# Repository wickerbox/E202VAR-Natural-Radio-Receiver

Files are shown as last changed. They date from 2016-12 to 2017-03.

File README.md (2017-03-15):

## Introduction

This project is based on the Explorer E202, with permission. 

Renato Romero put plans online for a Very Low Frequency (VLF) receiver capable between "a few Hz to beyond 10 kHz [which] makes it suitable to to receive radio signals of natural origin; signals not generated by human activity but by physical phenomena such as lightning and solar storms. Received signals are heard directly in your headset. The receiver amplifies the electric component of an electromagnetic signal."

His plans are <a href="http://www.vlf.it/romero2/explorer-e202.html">described on the vlf.it website</a>. The Explorer E202 is no longer available for sale.

He gave me permission to work from his schematic to design a new layout and make my own units. I am releasing all of my documents and process under the CERN Open Hardware License v1.2.

This is the original E202 full-size schematic.

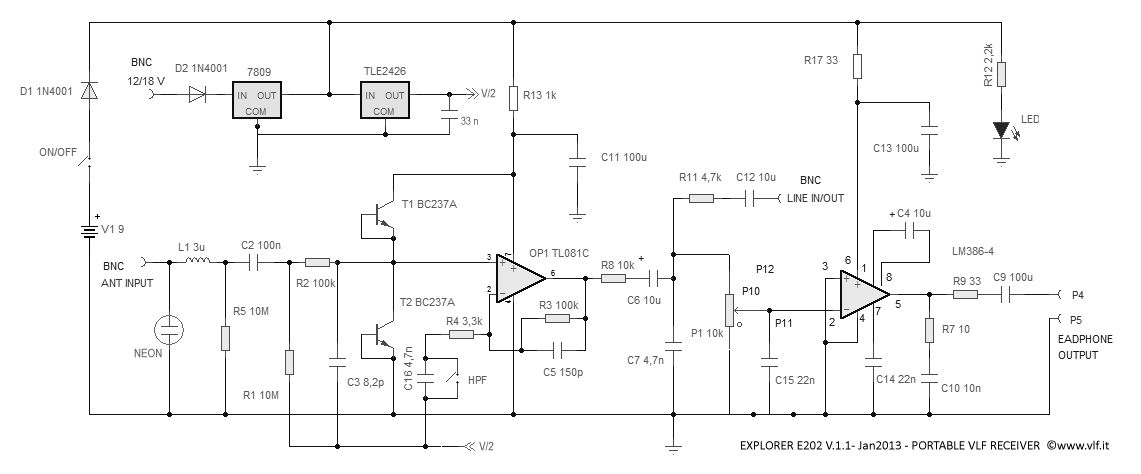
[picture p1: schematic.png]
Original schematic


\pagebreak

## Assembled v1.1 Receiver with Case

A fully assembled v1.1 in a box looked like this:

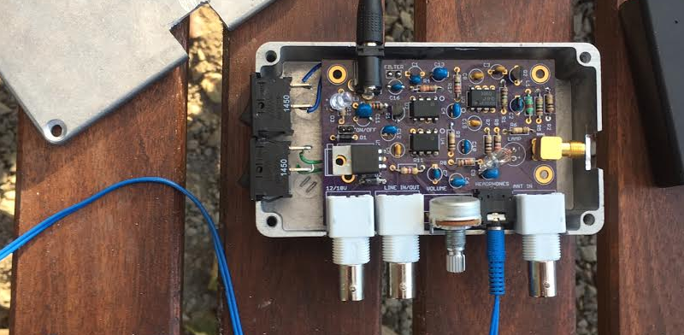
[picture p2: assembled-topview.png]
Assembled Top View v1.1


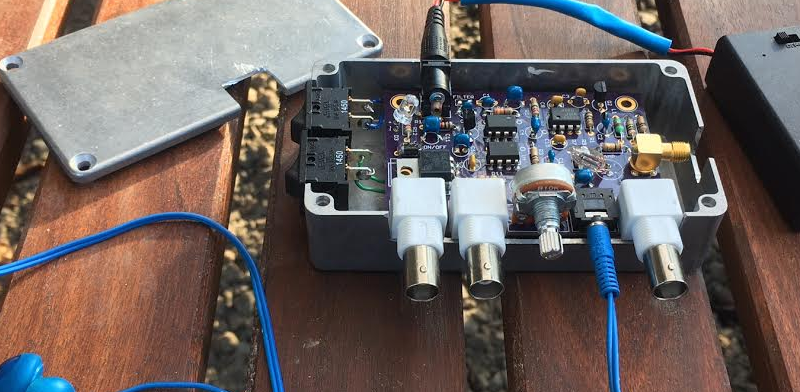
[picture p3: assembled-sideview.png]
Assembled Side View v1.1


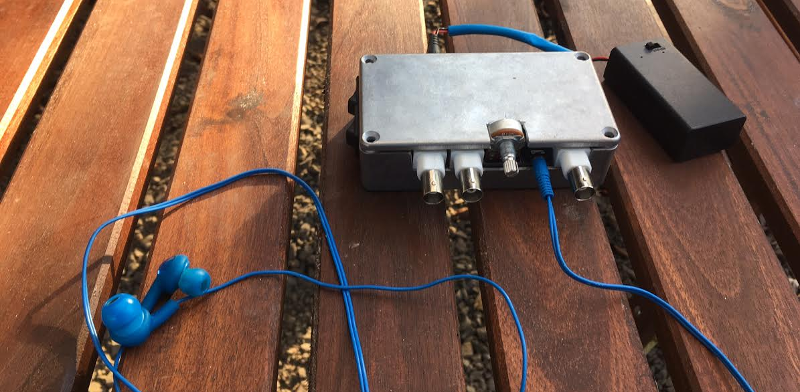
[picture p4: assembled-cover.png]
Assembled Cover v1.1


\pagebreak

## Assembled v1.4 Receiver Board

The final board for v1.4, which is the release version, looks like this: 

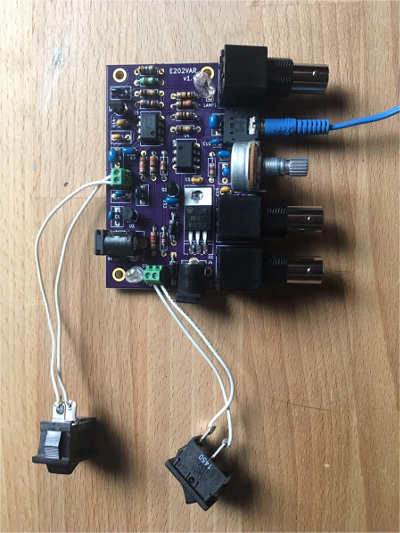
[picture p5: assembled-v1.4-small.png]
Assembled Final v1.4


\pagebreak

## Cost

Total cost of parts is about $25 if you order minimums. It's about $100 if you go to the next price break for most at qty=10, which is what I did since I'm prototyping, and what I recommend if you want to build two or more units. 

OSH Park: $35.35 for a set of three bare boards [<a href="https://oshpark.com/shared_projects/NvQSoarW">Shared Project #NvQSoarW</a>]

Digikey cart: $24.40 for parts for one board [<a href="http://www.digikey.com/short/32fqdm">Shared Cart #32fqdm</a>]

<!--- bom start --->
## Bill of Materials

|Ref|Qty|Description|Digikey PN|
|---|---|---|---|
|BNC1 BNC2 BNC3|3|CONN BNC JACK R/A 50 OHM PCB|A97555-ND|
|C1|1|CAP CER 0.033UF 50V C0G RADIAL|445-8490-ND|
|C10|1|CAP CER 10000PF 50V C0G RADIAL|445-8384-ND|
|C15 C14|2|CAP CER 0.022UF 50V X7R RADIAL|399-14089-1-ND|
|C16 C7|2|CAP CER 4700PF 50V C0G RADIAL|445-8585-ND|
|C2 C11|2|CAP CER 0.1UF 50V C0G RADIAL|445-8532-ND|
|C3|1|CAP CER 8.2PF 50V NP0 RADIAL|399-8923-ND|
|C5|1|CAP CER 150PF 50V NP0 RADIAL|BC1015CT-ND|
|C6 C12 C4|3|CAP CER 10UF 16V X5R RADIAL|445-8290-ND|
|C9 C13|2|CAP CER 100UF 6.3V X5R RADIAL|445-8441-ND|
|D1 D2|2|DIODE GEN PURP 50V 1A DO41|1N4001-TPMSCT-ND|
|D3|1|LED BLUE CLEAR 5MM ROUND T/H|C503B-BCS-CV0Z0461-ND|
|J1 J4|2|CONN PWR JACK 2.5X5.5MM HIGH CUR|PJ-202BH|
|J2 J5|2|CONN TERM SCREW GREEN 2.54MM 2POS TH|ED10561-ND|
|J3|1|CONN JACK STEREO R/A 3PIN 3.5MM|CP1-3523N-ND|
|L1|1|FIXED IND 3.3UH 575MA 300 MOHM|78F3R3J-RC-ND|
|LAMP1|1|LAMP NEON 6.2MM WIRE TERMINAL|A9A-ND|
|Q1 Q2|2|TRANS NPN 45V 0.1A TO-92|BC547BTACT-ND|
|R10|1|POT 10K OHM 1/5W PLASTIC LINEAR|987-1301-ND|
|R11|1|RES 4.7K OHM 1/4W 5% CF MINI|S4.7KQCT-ND|
|R12|1|RES 2.2K OHM 1/4W 5% CARBON FILM|CF14JT2K20CT-ND|
|R13|1|RES 1K OHM 1/4W 5% CF MINI|S1KQCT-ND|
|R4|1|RES 3.3K OHM 1/4W 5% CARBON FILM|CF14JT3K30CT-ND|
|R5 R1|2|RES 10M OHM 1/4W 5% CARBON FILM|CF14JT10M0CT-ND|
|R6 R2 R3|3|RES 100K OHM 1/4W 5% CARBON FILM|CF14JT100KCT-ND|
|R7|1|RES 10 OHM 1/4W 5% CARBON FILM|CF14JT10R0CT-ND|
|R8|1|RES 10K OHM 1/4W 5% CF MINI|S10KQCT-ND|
|R9 R17|2|RES 33 OHM 1/4W 5% CARBON FILM|CF14JT33R0CT-ND|
|U1|1|IC REG LDO 9V 1A MC7809 TO220AB|MC7809CTGOS-ND|
|U2|1|IC VREF GND REF ADJ TO92|296-6549-5-ND|
|U3|1|IC AUDIO PWR AMP LOW VOLT 8-DIP|NJM386D-ND|
|U4|1|IC OPAMP JFET 3MHZ DIP8|296-7203-5-ND|

<!--- bom end --->

\pagebreak

## Gerber Preview

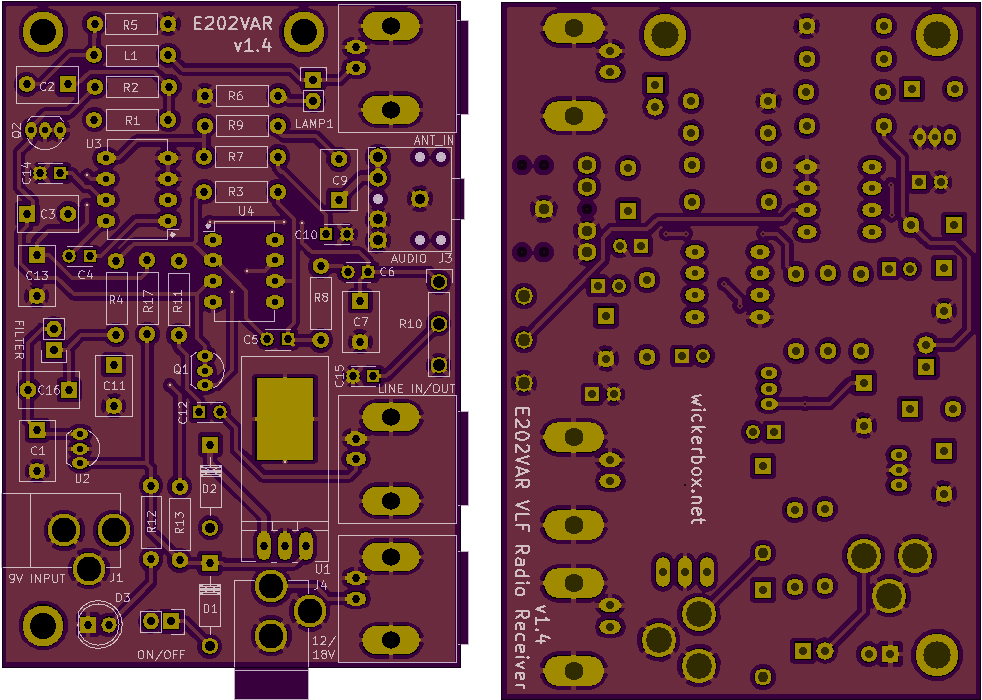
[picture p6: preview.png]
Gerber Preview


\pagebreak

## Assembly Diagram

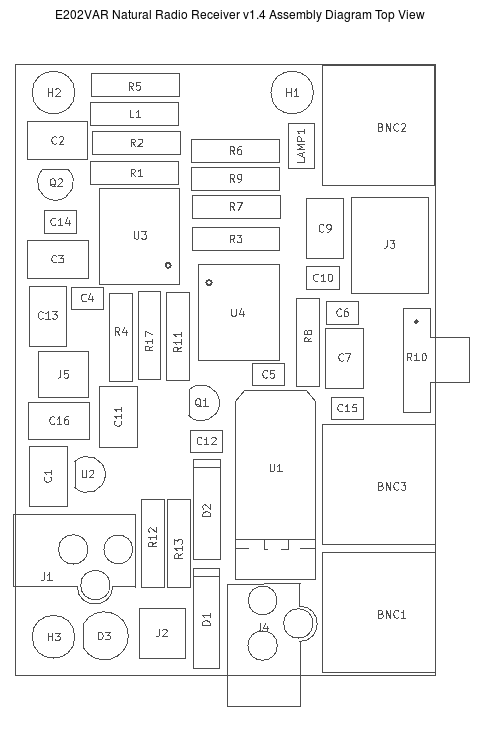
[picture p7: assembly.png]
Assembly Diagram


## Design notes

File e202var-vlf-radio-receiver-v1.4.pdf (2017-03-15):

E202VAR Natural Radio Receiver 1.4 | Wickerbox Electronics

# E202VAR Natural Radio Receiver v1.4

Open source variant of Romero’s E202 VLF Receiver

Introduction

This project is based on the Explorer E202, with permission.

Renato Romero put plans online for a Very Low Frequency (VLF) receiver capable between “a few Hz to beyond 10 kHz [which] makes it suitable to to receive radio signals of natural origin; signals not generated by human activity but by physical phenomena such as lightning and solar storms. Received signals are heard directly in your headset. The receiver amplifies the electric component of an electromagnetic signal.”

His plans are described on the vlf.it website. The Explorer E202 is no longer available for sale.

He gave me permission to work from his schematic to design a new layout and make my own units. I am releasing all of my documents and process under the CERN Open Hardware License v1.2.

This is the original E202 full-size schematic.


March 15, 2017 | http://wickerbox.net/

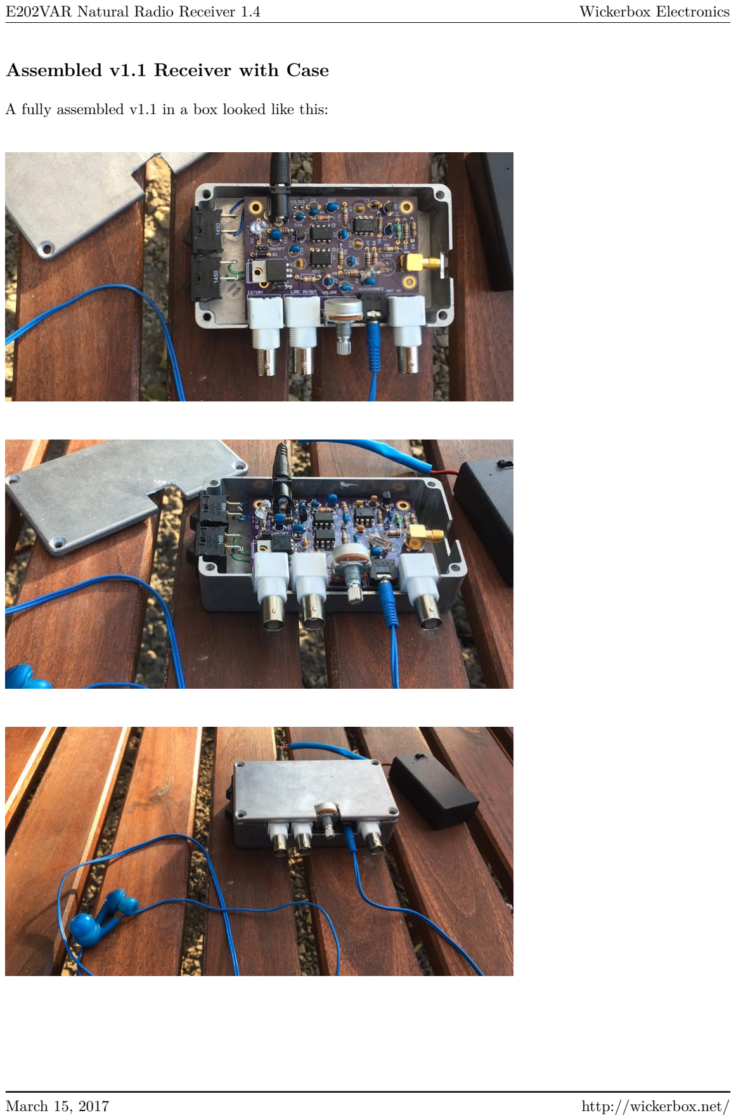
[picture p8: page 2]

Assembled v1.1 Receiver with Case

A fully assembled v1.1 in a box looked like this:

Assembled v1.4 Receiver Board

The final board for v1.4, which is the release version, looks like this:

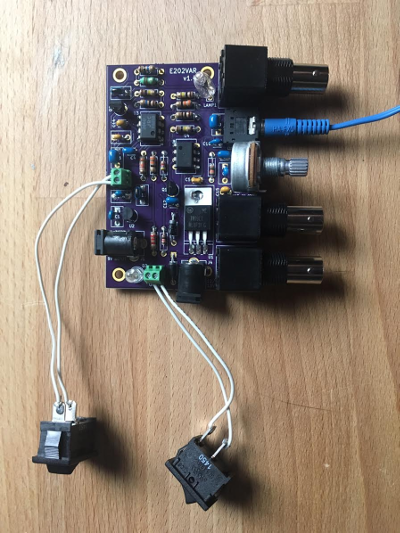
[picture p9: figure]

Cost

Total cost of parts is about $25 if you order minimums. It’s about $100 if you go to the next price break for most at qty=10, which is what I did since I’m prototyping, and what I recommend if you want to build two or more units.

OSH Park: $35.35 for a set of three bare boards [Shared Project #NvQSoarW]

Digikey cart: $24.40 for parts for one board [Shared Cart #32fqdm]

Bill of Materials

Ref | Qty | Description | Digikey PN
BNC1 BNC2 BNC3 | 3 | CONN BNC JACK R/A 50 OHM PCB | A97555-ND
C1 | 1 | CAP CER 0.033UF 50V C0G RADIAL | 445-8490-ND
C10 | 1 | CAP CER 10000PF 50V C0G RADIAL | 445-8384-ND
C15 C14 | 2 | CAP CER 0.022UF 50V X7R RADIAL | 399-14089-1-ND
C16 C7 | 2 | CAP CER 4700PF 50V C0G RADIAL | 445-8585-ND
C2 C11 | 2 | CAP CER 0.1UF 50V C0G RADIAL | 445-8532-ND
C3 | 1 | CAP CER 8.2PF 50V NP0 RADIAL | 399-8923-ND
C5 | 1 | CAP CER 150PF 50V NP0 RADIAL | BC1015CT-ND
C6 C12 C4 | 3 | CAP CER 10UF 16V X5R RADIAL | 445-8290-ND
C9 C13 | 2 | CAP CER 100UF 6.3V X5R RADIAL | 445-8441-ND
D1 D2 | 2 | DIODE GEN PURP 50V 1A DO41 | 1N4001-TPMSCT-ND
D3 | 1 | LED BLUE CLEAR 5MM ROUND T/H | C503B-BCS-CV0Z0461-ND
J1 J4 | 2 | CONN PWR JACK 2.5X5.5MM HIGH CUR | PJ-202BH
J2 J5 | 2 | CONN TERM SCREW GREEN 2.54MM 2POS TH | ED10561-ND
J3 | 1 | CONN JACK STEREO R/A 3PIN 3.5MM | CP1-3523N-ND
L1 | 1 | FIXED IND 3.3UH 575MA 300 MOHM | 78F3R3J-RC-ND
LAMP1 | 1 | LAMP NEON 6.2MM WIRE TERMINAL | A9A-ND
Q1 Q2 | 2 | TRANS NPN 45V 0.1A TO-92 | BC547BTACT-ND
R10 | 1 | POT 10K OHM 1/5W PLASTIC LINEAR | 987-1301-ND
R11 | 1 | RES 4.7K OHM 1/4W 5% CF MINI | S4.7KQCT-ND
R12 | 1 | RES 2.2K OHM 1/4W 5% CARBON FILM | CF14JT2K20CT-ND
R13 | 1 | RES 1K OHM 1/4W 5% CF MINI | S1KQCT-ND
R4 | 1 | RES 3.3K OHM 1/4W 5% CARBON FILM | CF14JT3K30CT-ND
R5 R1 | 2 | RES 10M OHM 1/4W 5% CARBON FILM | CF14JT10M0CT-ND
R6 R2 R3 | 3 | RES 100K OHM 1/4W 5% CARBON FILM | CF14JT100KCT-ND
R7 | 1 | RES 10 OHM 1/4W 5% CARBON FILM | CF14JT10R0CT-ND
R8 | 1 | RES 10K OHM 1/4W 5% CF MINI | S10KQCT-ND
R9 R17 | 2 | RES 33 OHM 1/4W 5% CARBON FILM | CF14JT33R0CT-ND
U1 | 1 | IC REG LDO 9V 1A MC7809 TO220AB | MC7809CTGOS-ND
U2 | 1 | IC VREF GND REF ADJ TO92 | 296-6549-5-ND
U3 | 1 | IC AUDIO PWR AMP LOW VOLT 8-DIP | NJM386D-ND
U4 | 1 | IC OPAMP JFET 3MHZ DIP8 | 296-7203-5-ND

Gerber Preview


Assembly Diagram

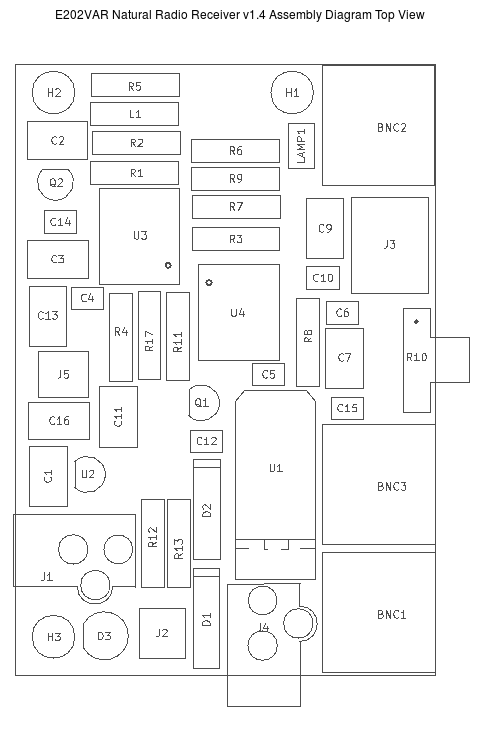
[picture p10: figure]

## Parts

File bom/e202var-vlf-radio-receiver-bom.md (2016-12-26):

|Ref|Qty|Description|Digikey PN|
|---|---|---|---|
|BNC1 BNC2 BNC3|3|CONN BNC JACK R/A 50 OHM PCB|A97555-ND|
|C1|1|CAP CER 0.033UF 50V C0G RADIAL|445-8490-ND|
|C10|1|CAP CER 10000PF 50V C0G RADIAL|445-8384-ND|
|C16 C7|2|CAP CER 4700PF 50V C0G RADIAL|445-8585-ND|
|C2 C11|2|CAP CER 0.1UF 50V C0G RADIAL|445-8532-ND|
|C3|1|CAP CER 8.2PF 50V NP0 RADIAL|399-8923-ND|
|C5 C15 C8|3|CAP CER 150PF 50V NP0 RADIAL|BC1015CT-ND|
|C6 C12 C4|3|CAP CER 10UF 16V X5R RADIAL|445-8290-ND|
|C9 C13|2|CAP CER 100UF 6.3V X5R RADIAL|445-8441-ND|
|D1 D2|2|DIODE GEN PURP 50V 1A DO41|1N4001-TPMSCT-ND|
|D3|1|LED BLUE CLEAR 5MM ROUND T/H|C503B-BCS-CV0Z0461-ND|
|J1 J4|2|CONN PWR JACK 2.5X5.5MM HIGH CUR|PJ-202BH|
|J2 J5|2|CONN TERM SCREW GREEN 2.54MM 2POS TH|ED10561-ND|
|J3|1|CONN JACK STEREO R/A 3PIN 3.5MM|CP1-3523N-ND|
|L1|1|FIXED IND 3.3UH 575MA 300 MOHM|78F3R3J-RC-ND|
|LAMP1|1|LAMP NEON 6.2MM WIRE TERMINAL|A9A-ND|
|Q1 Q2|2|TRANS NPN 45V 0.1A TO-92|BC547BTACT-ND|
|R10|1|POT 10K OHM 1/5W PLASTIC LINEAR|987-1301-ND|
|R11|1|RES 4.7K OHM 1/4W 5% CF MINI|S4.7KQCT-ND|
|R12|1|RES 2.2K OHM 1/4W 5% CARBON FILM|CF14JT2K20CT-ND|
|R13|1|RES 1K OHM 1/4W 5% CF MINI|S1KQCT-ND|
|R4|1|RES 3.3K OHM 1/4W 5% CARBON FILM|CF14JT3K30CT-ND|
|R5 R1|2|RES 10M OHM 1/4W 5% CARBON FILM|CF14JT1M00CT-ND|
|R6 R2 R3|3|RES 100K OHM 1/4W 5% CARBON FILM|CF14JT100KCT-ND|
|R7|1|RES 10 OHM 1/4W 5% CARBON FILM|CF14JT10R0CT-ND|
|R8|1|RES 10K OHM 1/4W 5% CF MINI|S10KQCT-ND|
|R9 R17|2|RES 33 OHM 1/4W 5% CARBON FILM|CF14JT33R0CT-ND|
|SMA1|1|CONN SMA JACK R/A 50 OHM PCB|ARFX1232-ND|
|U1|1|IC REG LDO 9V 1A MC7809 TO220AB|MC7809CTGOS-ND|
|U2|1|IC VREF GND REF ADJ TO92|296-6549-5-ND|
|U3|1|IC AUDIO PWR AMP LOW VOLT 8-DIP|NJM386D-ND|
|U4|1|IC OPAMP JFET 3MHZ DIP8|296-7203-5-ND|

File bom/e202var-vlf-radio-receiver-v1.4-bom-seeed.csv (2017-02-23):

Location | MPN/Seeed SKU | Quantity
BNC1 BNC2 BNC3 | 1-1634612-0 | 3
C1 | FK24C0G1H333J | 1
C10 | FK18C0G1H103J | 1
C15 C14 | C315C223K5R5TA7303 | 2
C16 C7 | FK28C0G1H472J | 2
C2 C11 | FK26C0G1H104J | 2
C3 | C317C829D5G5TA | 1
C5 | K151J15C0GF5TL2 | 1
C6 C12 C4 | FK14X5R1C106K | 3
C9 C13 | FK20X5R0J107M | 2
D1 D2 | 1N4001-TP | 2
D3 | C503B-BCS-CV0Z0461 | 1
J1 J4 | PJ-202BH | 2
J2 J5 | OSTVN02A150 | 2
J3 | SJ1-3523N | 1
L1 | 78F3R3J-RC | 1
LAMP1 | A9A | 1
Q1 Q2 | BC547BTA | 2
R10 | P160KN-0QC15B10K | 1
R11 | CFM14JT4K70 | 1
R12 | CF14JT2K20 | 1
R13 | CFM14JT1K00 | 1
R4 | CF14JT3K30 | 1
R5 R1 | CF14JT10M0CT-ND | 2
R6 R2 R3 | CF14JT100K | 3
R7 | CF14JT10R0 | 1
R8 | CFM14JT10K0 | 1
R9 R17 | CF14JT33R0 | 2
U1 | MC7809CTG | 1
U2 | TLE2426ILP | 1
U3 | NJM386D | 1
U4 | TL081CP | 1

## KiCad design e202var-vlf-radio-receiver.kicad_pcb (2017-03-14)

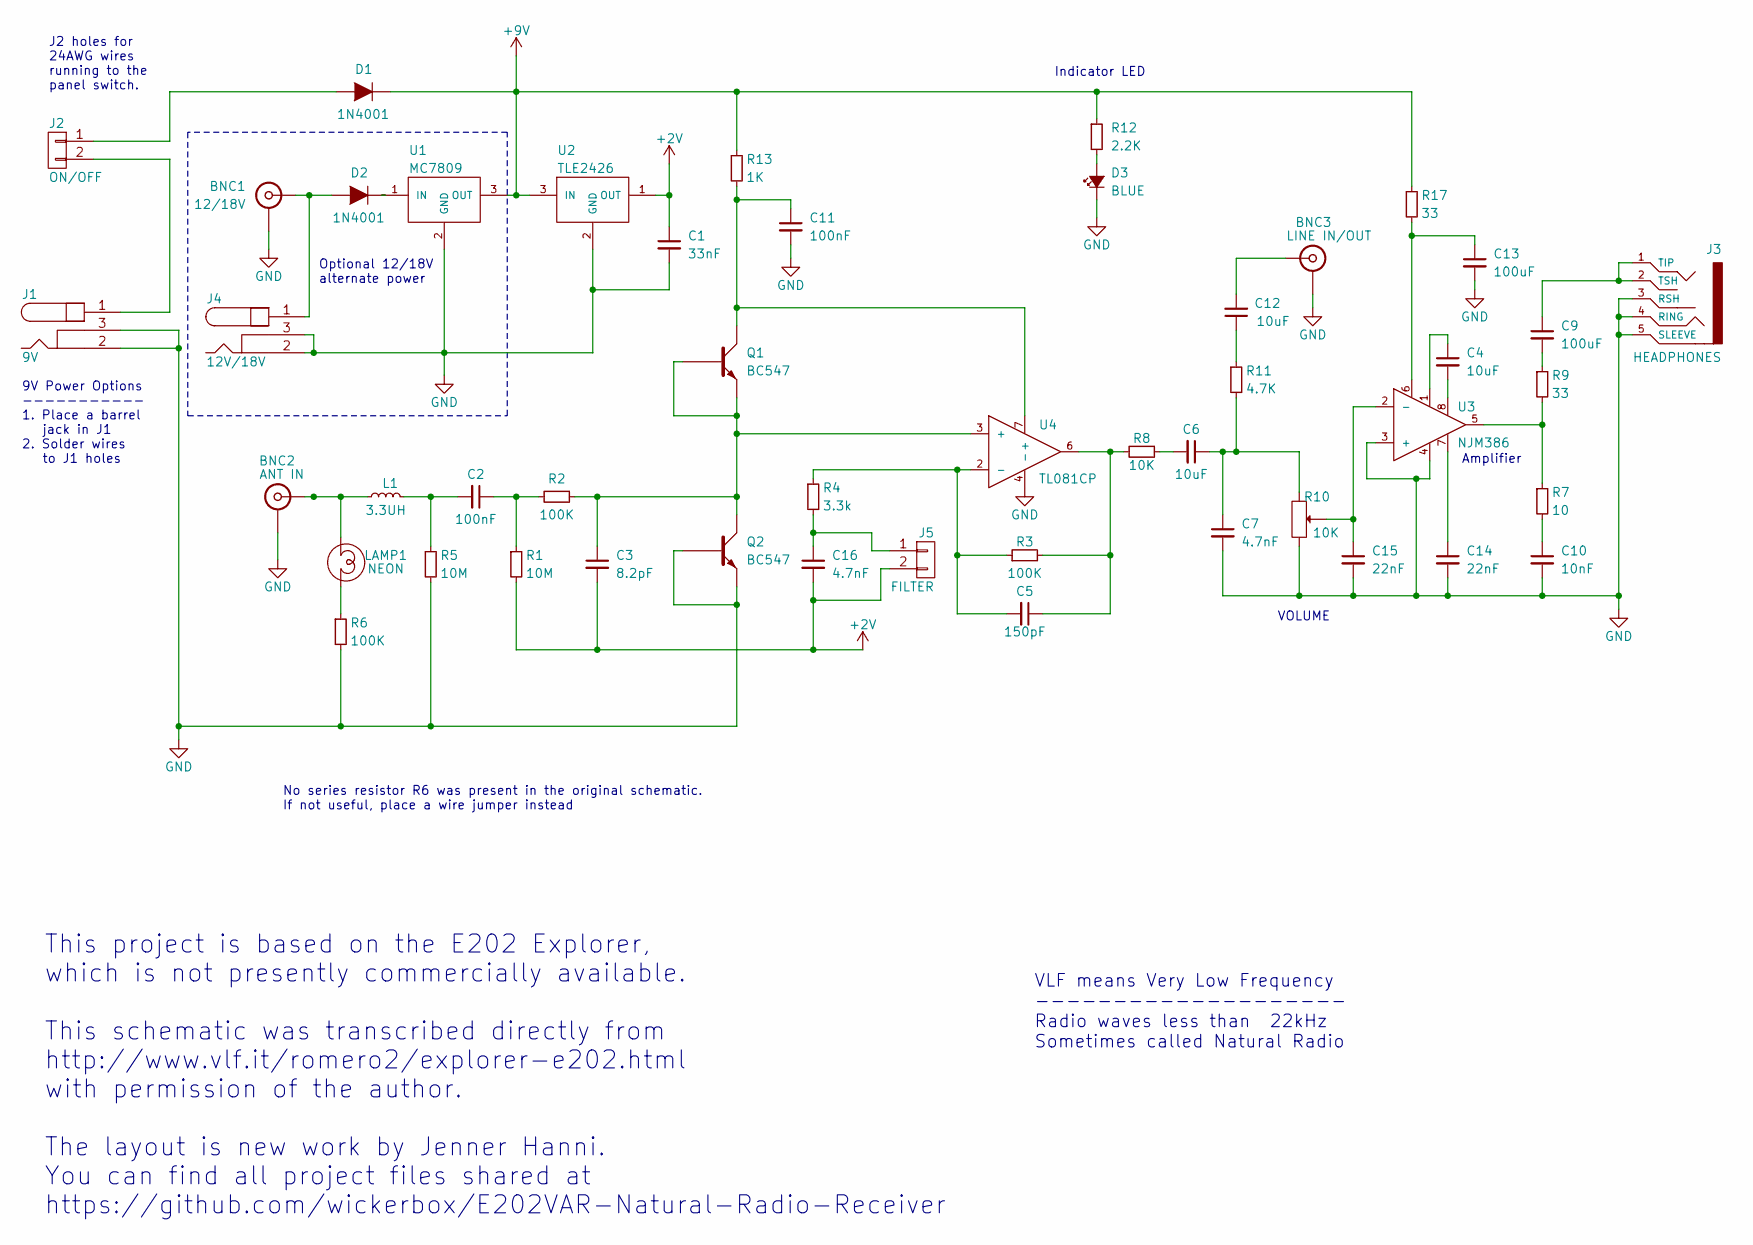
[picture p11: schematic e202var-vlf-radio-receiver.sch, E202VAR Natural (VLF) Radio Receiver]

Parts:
BNC1: 12/18V; CONN-BNC-TECONN-1-1634612-0
BNC2: ANT IN; CONN-BNC-TECONN-1-1634612-0
BNC3: LINE IN/OUT; CONN-BNC-TECONN-1-1634612-0
C1: 33nF; CAP-DISC-D7.5MM-P5MM
C2, C11: 100nF; CAP-DISC-D7.5MM-P5MM
C3: 8.2pF; CAP-DISC-D7.5MM-P5MM
C4, C6, C12: 10uF; CAP-DISC-D3MM-P2.5MM
C5: 150pF; CAP-DISC-D3MM-P2.5MM
C7, C16: 4.7nF; CAP-DISC-D7.5MM-P5MM
C9, C13: 100uF; CAP-DISC-D7.5MM-P5MM
C10: 10nF; CAP-DISC-D3MM-P2.5MM
C14, C15: 22nF; CAP-DISC-D3MM-P2.5MM
D1, D2: 1N4001; DIODE-DO-41
D3: BLUE; LED-D5MM-2PIN
J1: 9V; CONN-BARREL-JACK-2.5x5.5MM-TH
J2: ON/OFF; CONN-ONSHORE-SCREW-GREEN-2PIN-TH
J3: HEADPHONES; SJ1-3523N
J4: 12V/18V; CONN-BARREL-JACK-2.5x5.5MM-TH
J5: FILTER; CONN-ONSHORE-SCREW-GREEN-2PIN-TH
L1: 3.3UH; RES-CARBONFILM-7MM
LAMP1: NEON; CONN-HEADER-STRAIGHT-P2.54MM-1x02
Q1, Q2: BC547; TO-92-INLINE-NARROW-OVAL
R1, R5: 10M; RES-CARBONFILM-7MM
R2, R3, R6: 100K; RES-CARBONFILM-7MM
R4: 3.3k; RES-CARBONFILM-7MM
R7: 10; RES-CARBONFILM-7MM
R8: 10K; RES-CARBONFILM-7MM
R9, R17: 33; RES-CARBONFILM-7MM
R10: 10K; RES-TRIMPOT-TTELEC-P160-TH
R11: 4.7K; RES-CARBONFILM-7MM
R12: 2.2K; RES-CARBONFILM-7MM
R13: 1K; RES-CARBONFILM-7MM
U1: MC7809; TO-220-NEUTRAL123-HORZ-LONGPADS
U2: TLE2426; TO-92-INLINE-NARROW-OVAL
U3: NJM386; DIP-8-W7.62MM-LONGPADS
U4: TL081CP; DIP-8-W7.62MM-LONGPADS

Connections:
+2V: C1.1, C3.2, C16.2, J5.2, R1.2, U2.1 (OUT)
+9V: D1.1 (K), R12.1, R13.1, R17.1, U1.3 (OUT), U2.3 (IN)
GND: BNC1.2 (GND), BNC2.2 (GND), BNC3.2 (GND), C1.2, C7.2, C10.2, C11.2, C13.2, C14.2, C15.2, D3.1 (K), J1.2, J1.3, J3.3 (RSH), J3.4 (RING), J3.5 (SLEEVE), J4.2, J4.3, Q2.1 (B), Q2.2 (E), R5.2, R6.2, R10.3, U1.2 (GND), U2.2 (GND), U3.3 (+), U3.4, U4.4 (-)
unnamed: BNC1.1 (SIGNAL), D2.2 (A), J4.1
unnamed: BNC2.1 (SIGNAL), L1.1, LAMP1.1
unnamed: BNC3.1 (SIGNAL), C12.2
unnamed: C2.1, R1.1, R2.2
unnamed: C2.2, L1.2, R5.1
unnamed: C3.1, Q1.1 (B), Q1.2 (E), Q2.3 (C), R2.1, U4.3 (+)
unnamed: C4.1, U3.1
unnamed: C4.2, U3.8
unnamed: C5.1, R3.2, R8.2, U4.6
unnamed: C5.2, R3.1, R4.1, U4.2 (-)
unnamed: C6.1, C7.1, R10.1, R11.2
unnamed: C6.2, R8.1
unnamed: C9.1, J3.1 (TIP), J3.2 (TSH)
unnamed: C9.2, R9.1
unnamed: C10.1, R7.2
unnamed: C11.1, Q1.3 (C), R13.2, U4.7 (+)
unnamed: C12.1, R11.1
unnamed: C13.1, R17.2, U3.6
unnamed: C14.1, U3.7
unnamed: C15.1, R10.2, U3.2 (-)
unnamed: C16.1, J5.1, R4.2
unnamed: D1.2 (A), J2.1
unnamed: D2.1 (K), U1.1 (IN)
unnamed: D3.2 (A), R12.2
unnamed: J1.1, J2.2
unnamed: LAMP1.2, R6.1
unnamed: R7.1, R9.2, U3.5

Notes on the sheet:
J2 holes for 24AWG wires running to the panel switch.
Indicator LED
VOLUME
Optional 12/18V alternate power
9V Power Options ----------- 1. Place a barrel jack in J1 2. Solder wires to J1 holes
No series resistor R6 was present in the original schematic. If not useful, place a wire jumper instead
VLF means Very Low Frequency -------------------- Radio waves less than 22kHz Sometimes called Natural Radio
This project is based on the E202 Explorer, which is not presently commercially available. This schematic was transcribed directly from http://www.vlf.it/romero2/explorer-e202.html with permission of the author. The layout is new work by Jenner Hanni. You can find all project files shared at https: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
Amplifier

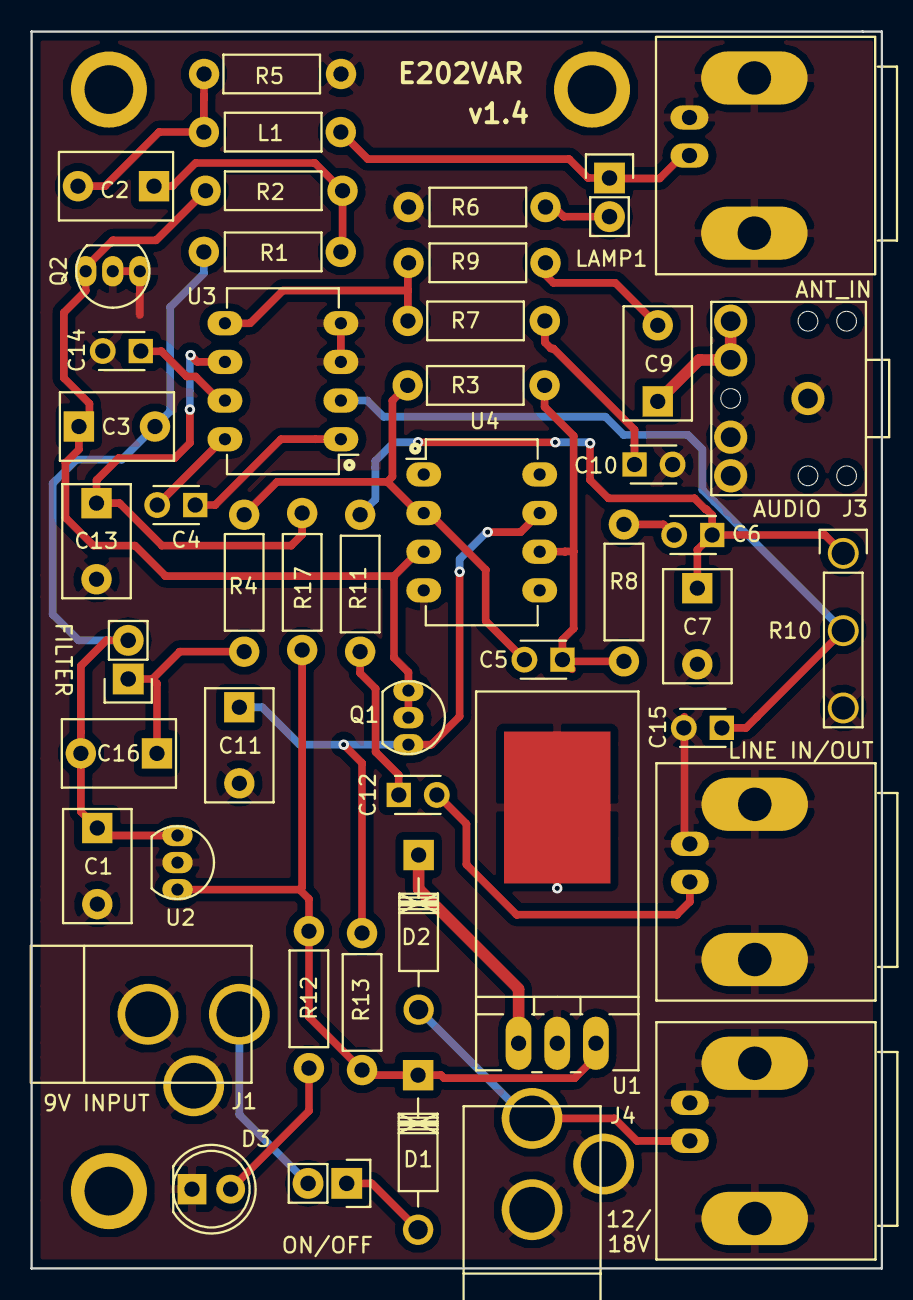
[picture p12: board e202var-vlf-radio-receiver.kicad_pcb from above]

Board: 2 copper layers, 55.9 x 81.3 mm, 51 parts (0 on the bottom side), 30 nets.

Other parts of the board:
H1, H2, H3: HOLE-PLATED-3.2MM

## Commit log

2015-10-16 Added BOM.
2015-10-20 Added notes, clarified BOM a little.
2015-10-20 Finished first pass of schematic. Ready for review.
    [e202-wickervar.sch]
2015-10-24 Changed name. Cleaned up schematic. Added notes and exported BOM. Need to compare.
    [vlf-receiver-v1.sch]
2015-10-24 Updated README.
    [e202var-receiver-v1.sch]
2015-10-24 Checking spaces in BOM.
2015-10-24 Finished capacitors and diodes.
2015-10-24 Added resistors.
2015-10-24 Parts selected! BOM created! (For now...)
2015-10-25 Changed R7 so all resistors are from same family.
2015-10-25 Changed R7, checked off verified BOM todo item.
2015-10-25 Changed LAMP(A) to a 4mm neon indicator. Added cost.
2015-10-25 Added e202var library and clean schematic.
    [e202var-receiver-v1.sch]
2015-10-25 Made sure README and BOM.md agree on final BOM.
2015-10-25 Updated schematic PNG image from schematic.
2015-10-25 Added frame. Regenerated image.
    [e202var-receiver-v1.sch]
2015-10-25 Placed components. Board size probably 2.22x3.18 inches. 5.25 for three at OSH Park.
    [e202var-receiver-v1.brd, e202var-receiver-v1.sch]
2015-10-25 Finished layout.
    [e202var-receiver-v1.brd]
2015-10-25 Added schematic, layout, and OSH Park preview images.
2015-10-25 Added CAM, DRU, clean BOM, library, and final of everything. Now we wait for Oct 30th.
    [e202var-receiver-v1.brd, e202var-receiver-v1.sch]
2015-12-19 Version 1.1 draft, awaiting last round of testing.
    [e202var-receiver-v1.1.brd, e202var-receiver-v1.1.sch]
2015-12-19 Getting the repo set up for v1.1
    [e202var-receiver-v1.1.brd, e202var-receiver-v1.1.sch, e202var-receiver-v1.brd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]
2016-12-06 Created Kicad schematic for v1.1.
    [e202var-vlf-radio-receiver.kicad_pcb, e202var-vlf-radio-receiver.sch]
2016-12-09 Rough part placement. Created README. Images made by gerbv are off-center.
    [e202var-vlf-radio-receiver-B.Cu.gbl, e202var-vlf-radio-receiver-B.Fab.gbr, e202var-vlf-radio-receiver-B.Mask.gbs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]
2016-12-10 Added parts. Ready for layout.
    [e202var-vlf-radio-receiver-B.Cu.gbl, e202var-vlf-radio-receiver-B.Fab.gbr, e202var-vlf-radio-receiver-B.Mask.gbs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]
2016-12-10 Ported the board to KiCad.
    [e202var-vlf-radio-receiver-B.Cu.gbl, e202var-vlf-radio-receiver-B.Fab.gbr, e202var-vlf-radio-receiver-B.Mask.gbs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]
2016-12-10 Release v1.2
    [e202var-receiver-v1.1.brd, e202var-receiver-v1.1.sch, e202var-receiver-v1.brd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]
2016-12-26 v1.3 fixes in place. Saving before running script.
    [e202var-vlf-radio-receiver-B.Cu.gbl, e202var-vlf-radio-receiver-B.Fab.gbr, e202var-vlf-radio-receiver-B.Mask.gbs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]
2016-12-26 Moved folders around.
    [e202var-vlf-radio-receiver-bom-digikey-qty-10.csv, e202var-vlf-radio-receiver-bom-digikey.csv, e202var-vlf-radio-receiver-bom-master.csv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]
2016-12-26 Playing with kingfisher.
    [e202var-vlf-radio-receiver-B.Cu.gbl, e202var-vlf-radio-receiver-B.Fab.gbr, e202var-vlf-radio-receiver-B.Mask.gbs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]
2016-12-27 v1.3 release.
    [e202var-vlf-radio-receiver-B.Cu.gbl, e202var-vlf-radio-receiver-B.Fab.gbr, e202var-vlf-radio-receiver-B.Mask.gbs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]
2016-12-27 Fix v1.3 PDF. Order boards.
    [e202var-vlf-radio-receiver-B.Cu.gbl, e202var-vlf-radio-receiver-B.Fab.gbr, e202var-vlf-radio-receiver-B.Mask.gbs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]
2017-02-23 Fixed several schematic issues.
    [e202var-vlf-radio-receiver.kicad_pcb]
2017-02-23 v1.4 because of silly schematic mistakes.
    [e202var-vlf-radio-receiver-B.Cu.gbl, e202var-vlf-radio-receiver-B.Fab.gbr, e202var-vlf-radio-receiver-B.Mask.gbs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]
2017-02-24 Added three mounting holes to v1.4. Release.
    [e202var-vlf-radio-receiver-B.Cu.gbl, e202var-vlf-radio-receiver-B.Mask.gbs, e202var-vlf-radio-receiver-B.Paste.gbp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]
2017-03-14 Release v1.4. Verified build. Project complete.
    [e202var-vlf-radio-receiver-B.Cu.gbl, e202var-vlf-radio-receiver-B.Mask.gbs, e202var-vlf-radio-receiver-B.Paste.gbp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]
2017-03-15 Added v1.4 assembled image.

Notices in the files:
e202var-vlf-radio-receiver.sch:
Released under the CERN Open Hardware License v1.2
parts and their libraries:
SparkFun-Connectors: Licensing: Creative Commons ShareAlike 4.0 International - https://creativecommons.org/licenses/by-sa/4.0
